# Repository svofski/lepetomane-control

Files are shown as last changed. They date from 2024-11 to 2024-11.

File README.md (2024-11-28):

# Pétocontrôle

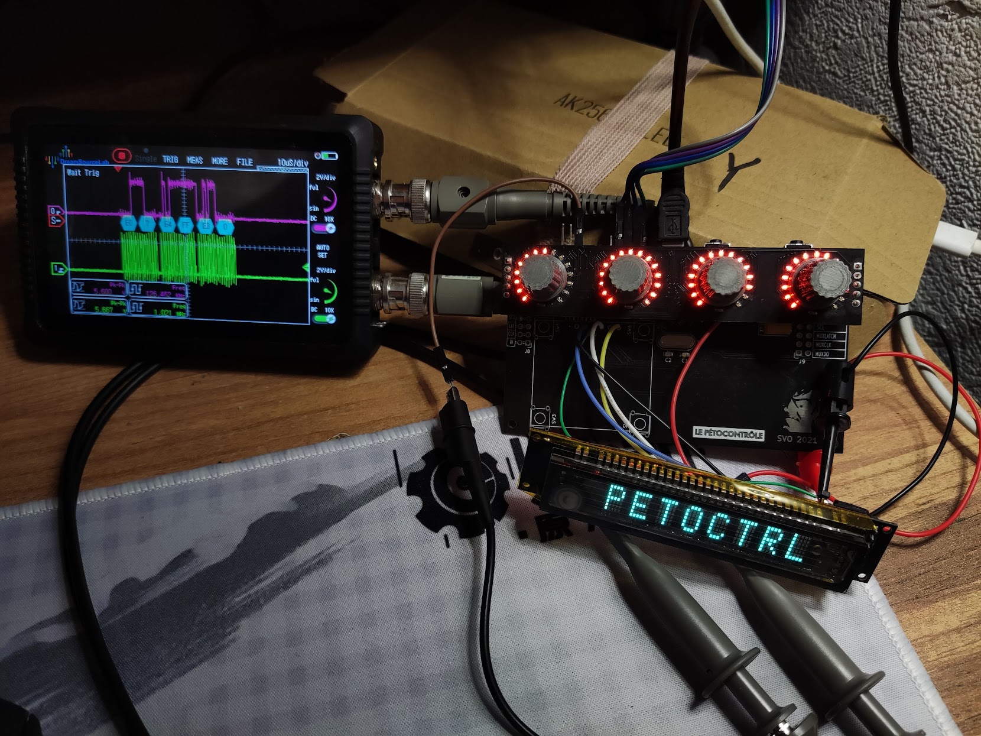
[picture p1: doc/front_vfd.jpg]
front


This is a MIDI control surface that sends CC messages when you turn the knobs. The main features are:

 * magnetic encoders (AS5600) with real potentiometer mechanics for ultra-smooth potentiometer-like feel
 * beautiful 0402 orange LEDs that show knob positions
 * Futaba 8-MD-06INKM VFD display

I wanted smooth feel encoders that work like proper potentiometers. These days everything is implemented using notchy encoders and although smooth input encoders do exist, they are somewhat uncommon.

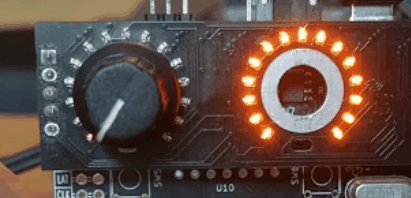
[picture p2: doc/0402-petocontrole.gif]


The design consists of two boards, the bottom one has MCU and the sensors, the top "mezzanine" board has the shift registers for the LEDs and holes for the knob shafts. 
The knobs are mechanisms ripped out from cheap potentiometers, they have little magnets glued into their bottom ends. Several boards can in theory attach to one another to form long strips of knobs.

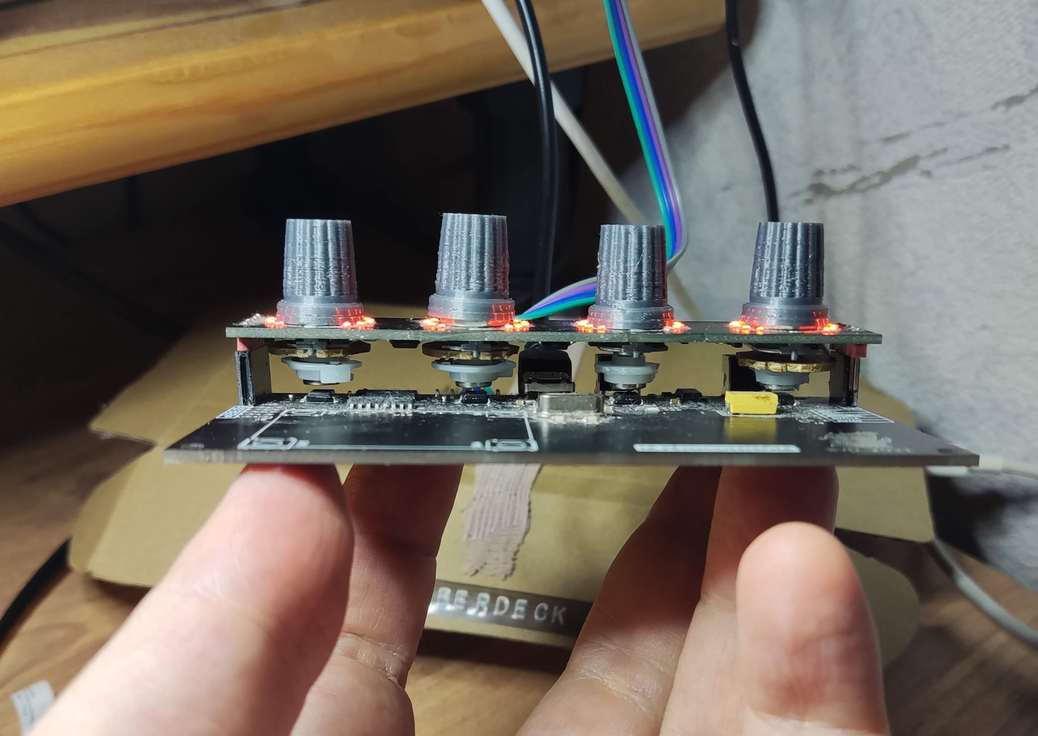
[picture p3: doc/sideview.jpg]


## Design files
 * [Schematics and PCB (KiCanvas)](https://kicanvas.org/?github=https://github.com/svofski/lepetomane-control/tree/master/kicad)

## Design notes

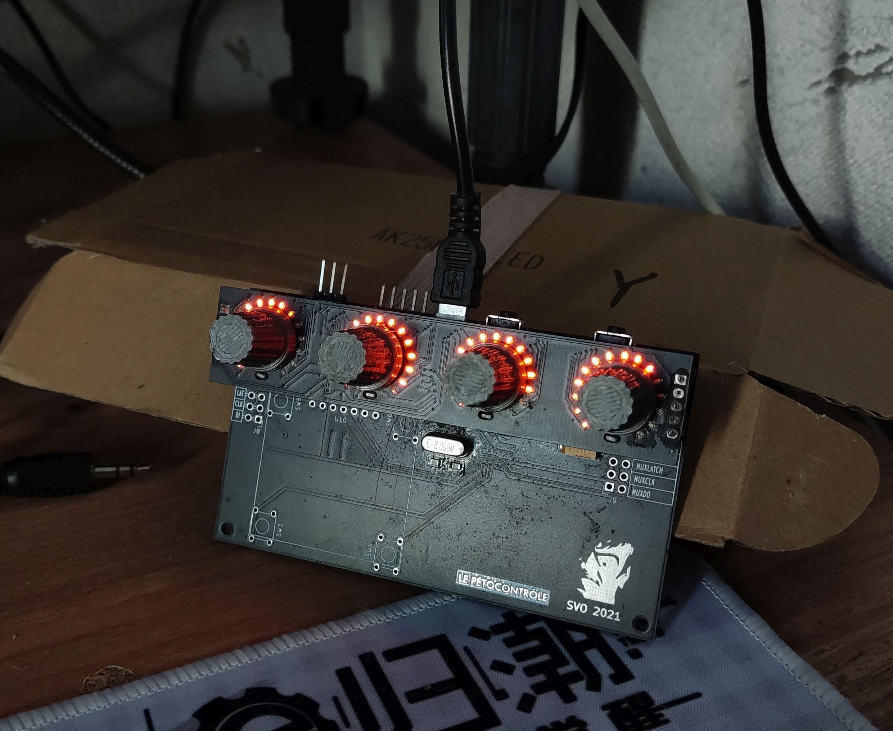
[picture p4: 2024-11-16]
doc/front.jpg

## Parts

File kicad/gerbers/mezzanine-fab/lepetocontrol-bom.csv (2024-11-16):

Comment | Designator | Footprint | LCSC
LED | D1,D2,D3,D4,D5,D6,D7,D8,D9,D10,D11,D12,D13,D14,D15,D17,D18,D19,D20,D21,D22,D23,D24,D25,D26,D27,D28,D29,D30,D31,D33,D34,D35,D36,D37,D38,D39,D40,D41,D42,D43,D44,D45,D46,D47,D49,D50,D51,D52,D53,D54,D55,D56,D57,D58,D59,D60,D61,D62,D63 | LED_0402 | C130720

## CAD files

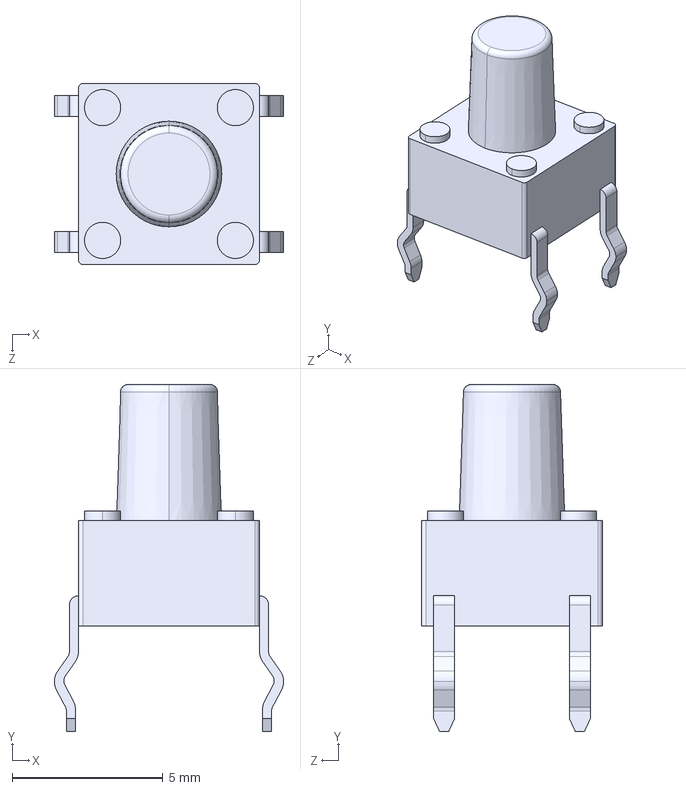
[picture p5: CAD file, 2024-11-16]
kicad/shapes3D/6x6button.STEP
7.60 x 11.5 x 6.00 mm

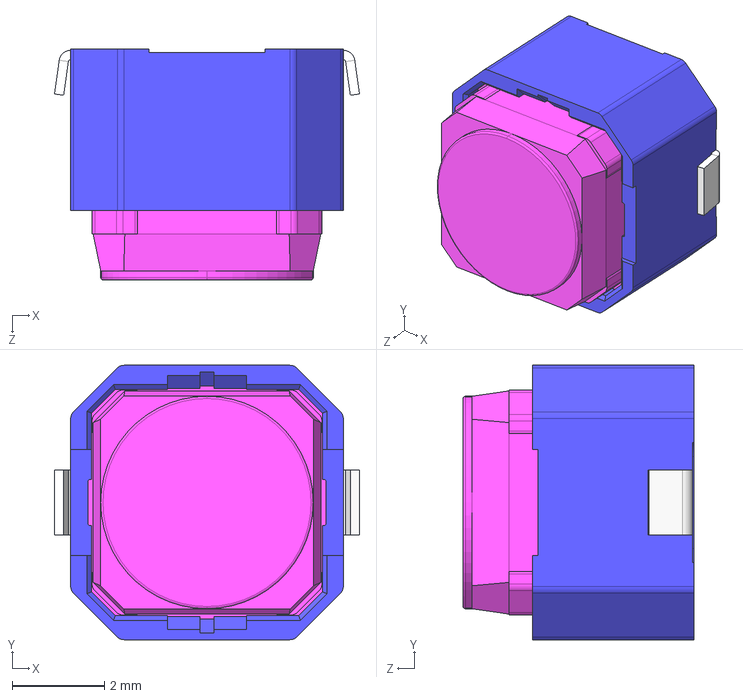
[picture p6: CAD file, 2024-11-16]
kicad/shapes3D/SKPMAM.STEP
6.60 x 5.94 x 5.00 mm

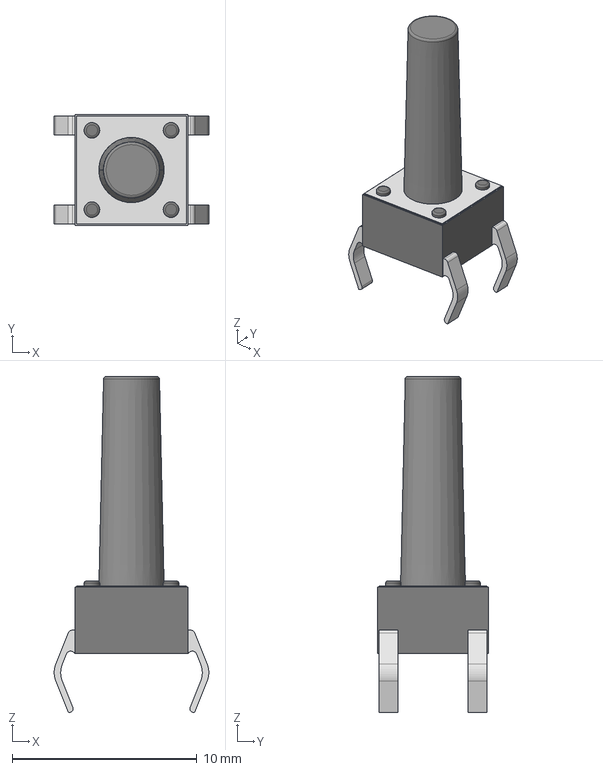
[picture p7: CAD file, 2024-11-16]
kicad/shapes3D/Tactal Switch -Thru (6mmx 6mmx15.0mm).stp
8.37 x 5.99 x 18.2 mm

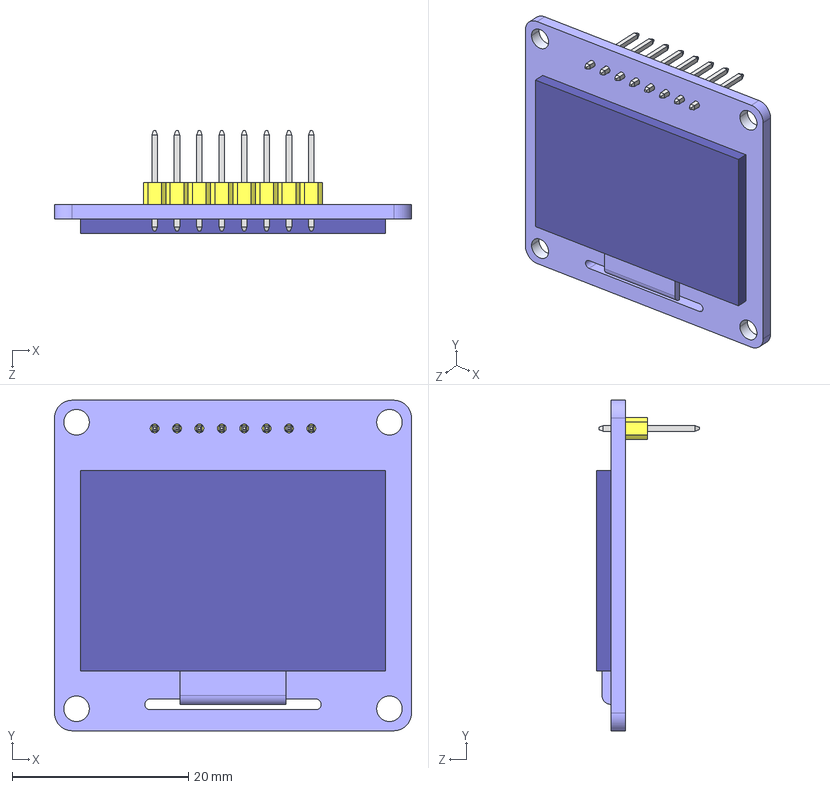
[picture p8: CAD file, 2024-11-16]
kicad/shapes3D/OLED_1.3inch_sh1106.STEP
40.5 x 37.5 x 11.6 mm
OLED_pcb_1.3
2.54mm_pin_header x 8

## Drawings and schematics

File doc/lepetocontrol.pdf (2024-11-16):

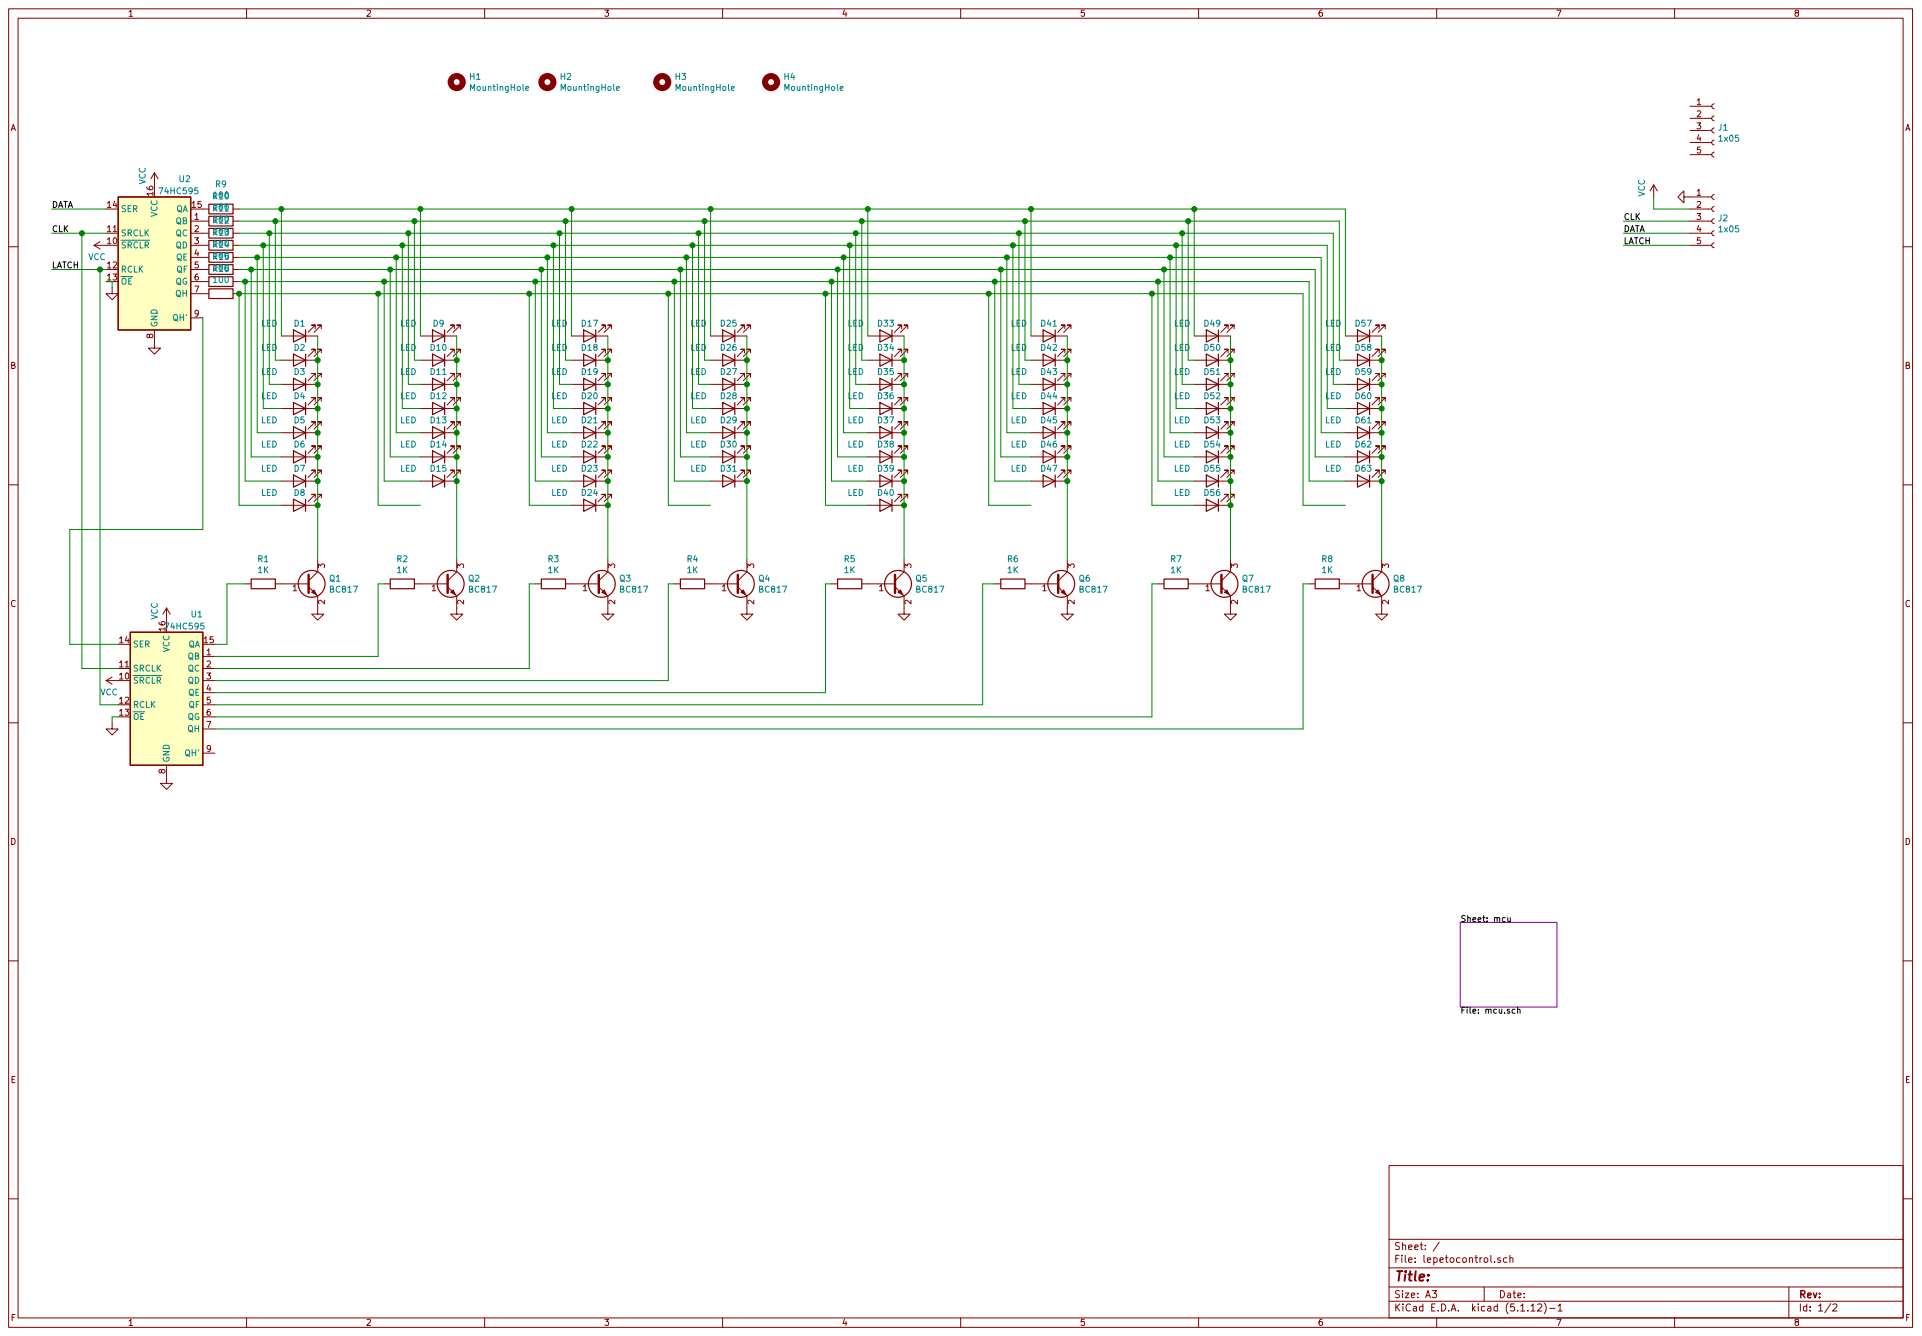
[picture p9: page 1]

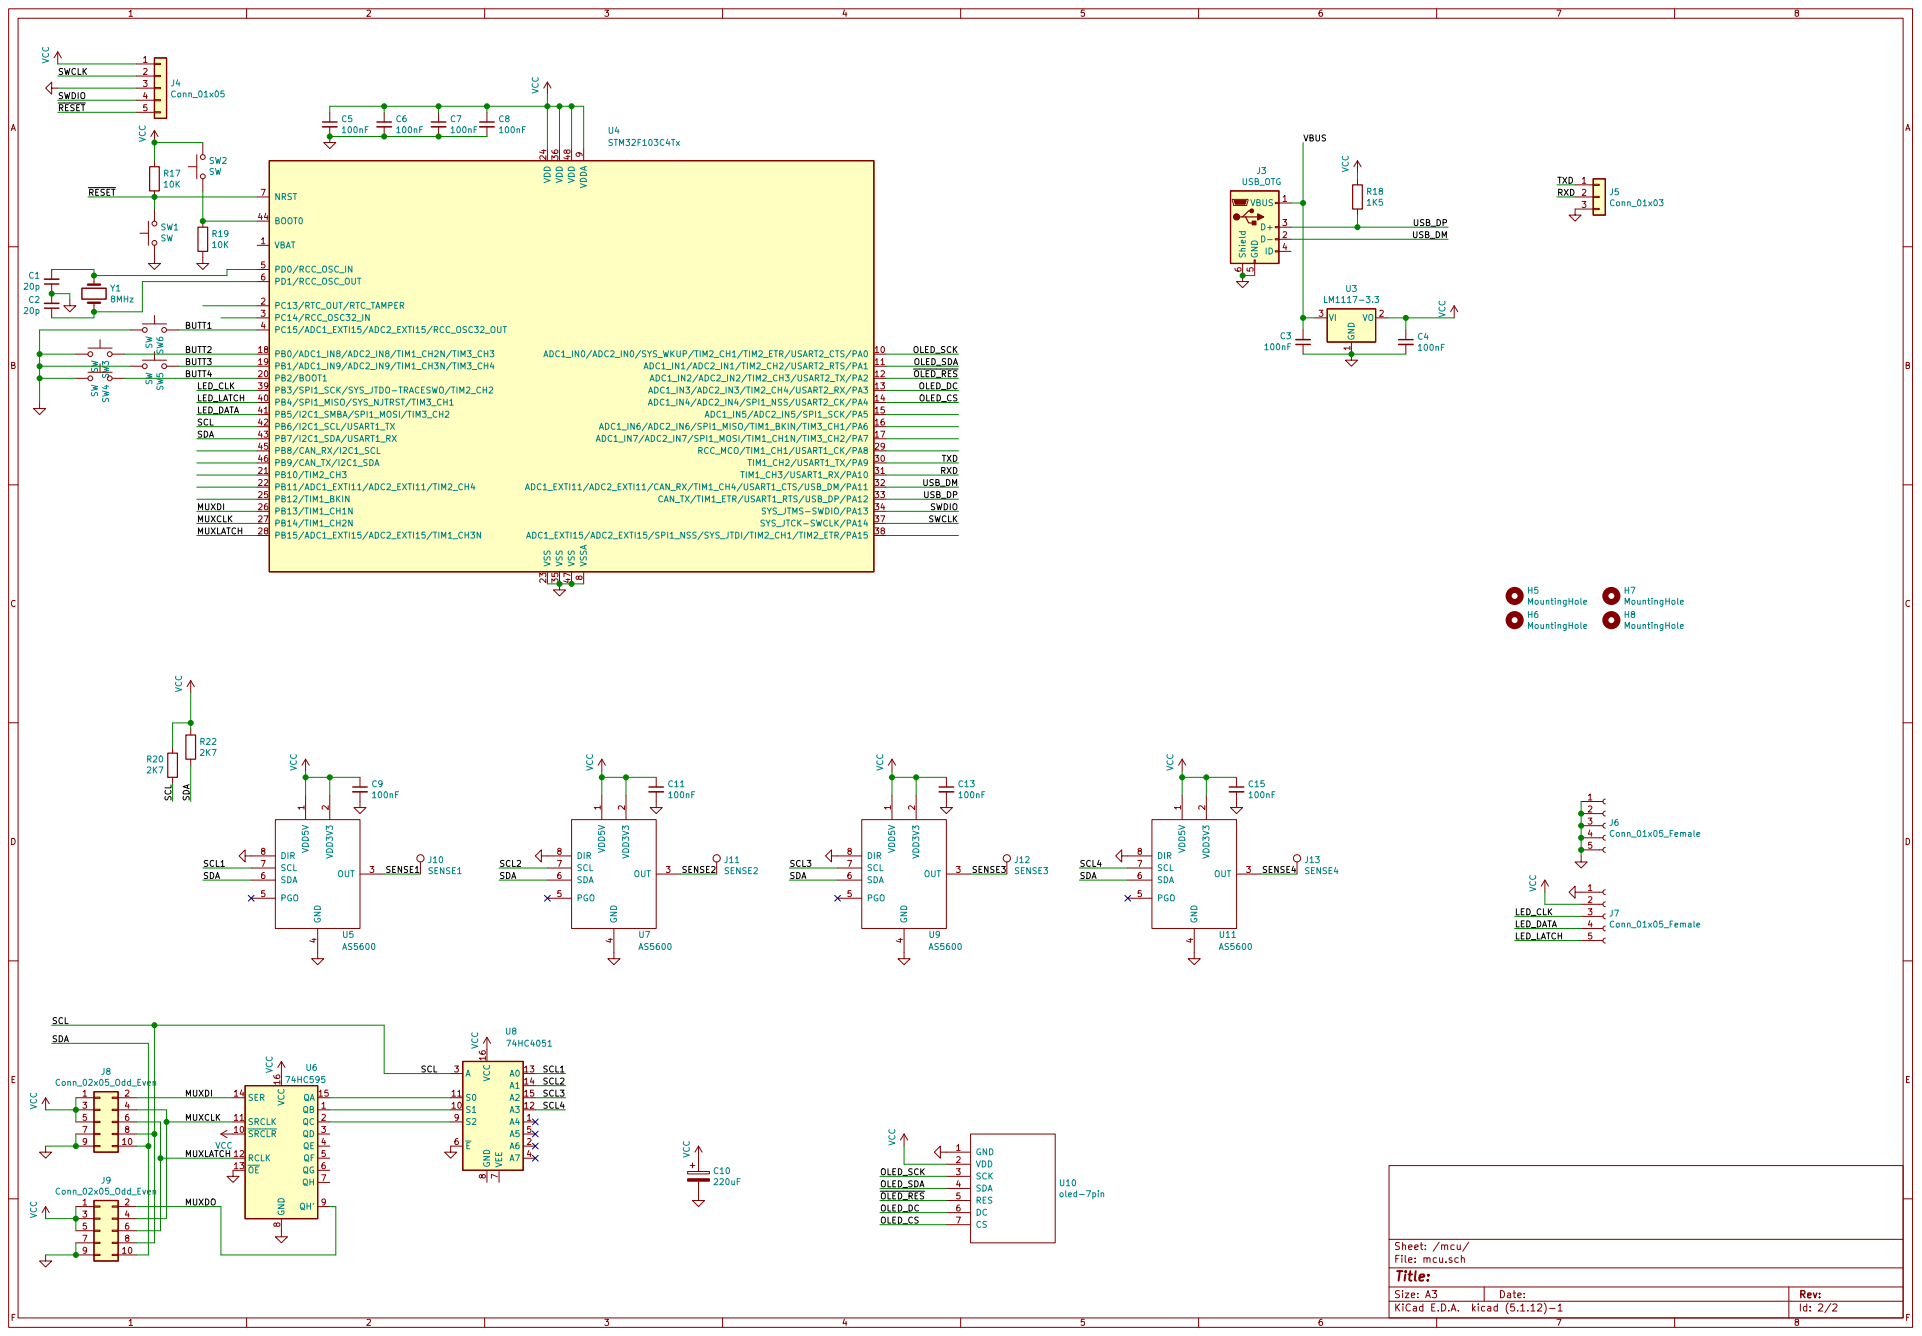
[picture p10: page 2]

9 VSS 23 VSS 35 VSS 47 VSSA

4 PGO 5 SDA 6 SCL 7 DIR 8 U7AS5600 VCC VCC

4 PGO 5 SDA 6 SCL 7 DIR 8 U9AS5600 VCCR20

4 PGO 5 SDA 6 SCL 7 DIR 8 U11 AS5600 VCC

4 PGO 5 SDA 6 SCL 7 DIR 8 U5AS5600 VDD5V

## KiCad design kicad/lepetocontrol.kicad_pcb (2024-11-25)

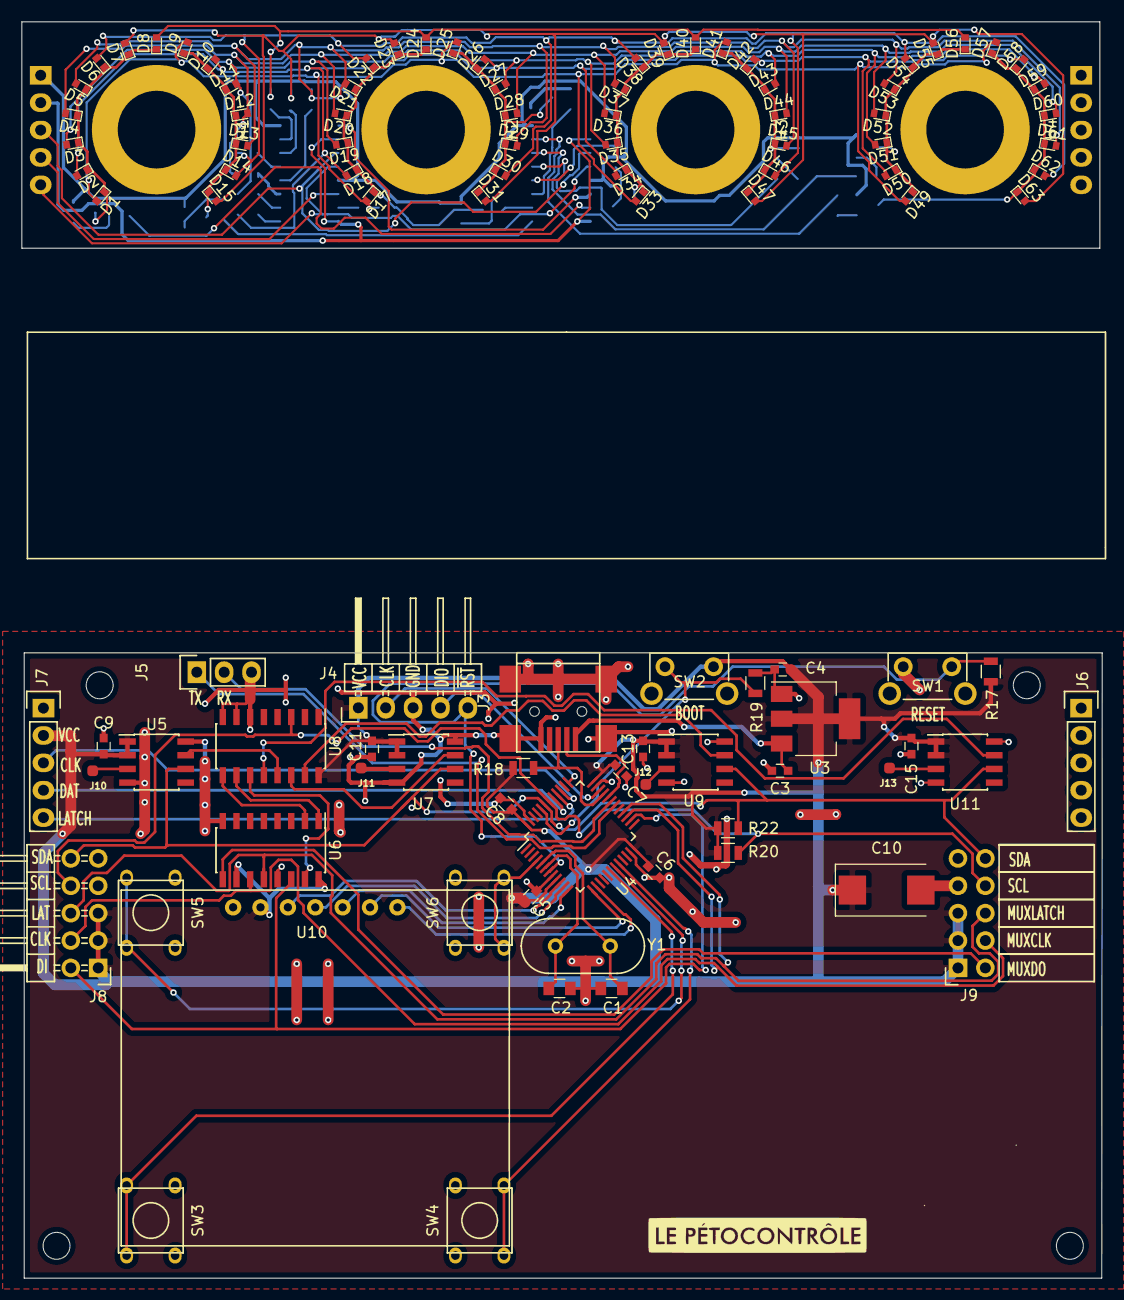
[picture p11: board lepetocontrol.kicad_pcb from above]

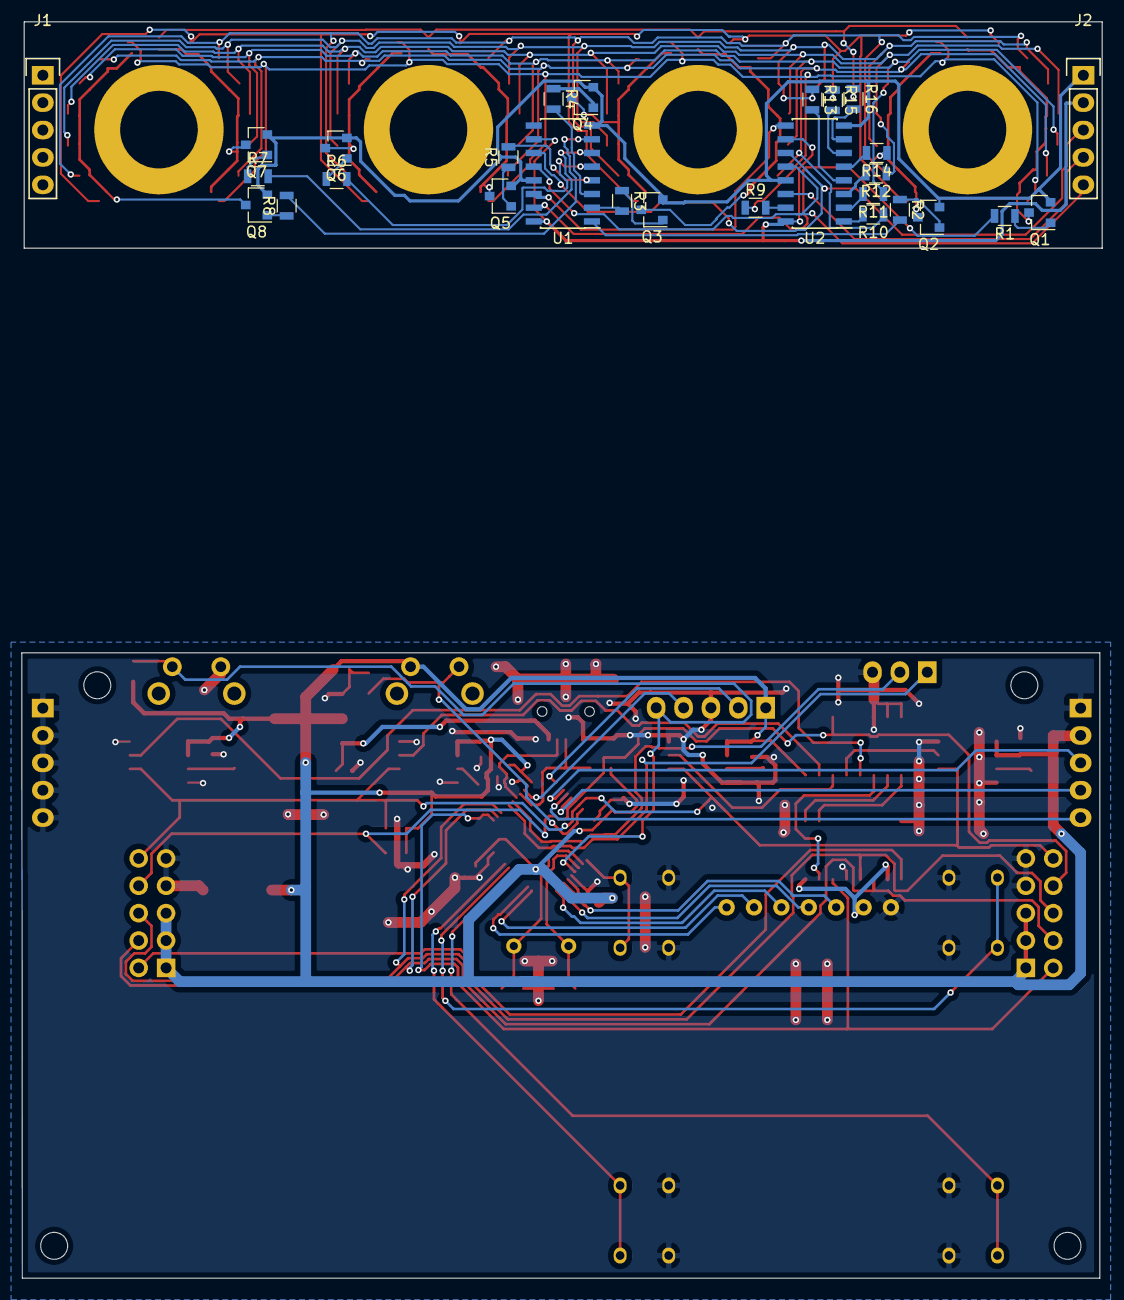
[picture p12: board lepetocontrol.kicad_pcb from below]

Board: 2 copper layers, 100.2 x 116.5 mm, 142 parts (28 on the bottom side), 86 nets.

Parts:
C1, C2: 20p; C_0805
C3, C4, C5, C6, C7, C8, C9, C11, C13, C15: 100nF; C_0603
C10: 220uF; CP_Tantalum_Case-D_EIA-7343-31_Reflow
D1, D2, D3, D4, D5, D6, D7, D8, D9, D10, D11, D12, D13, D14, D15, D17, D18, D19, D20, D21, D22, D23, D24, D25, D26, D27, D28, D29, D30, D31, D33, D34, D35, D36, D37, D38, D39, D40, D41, D42, D43, D44, D45, D46, D47, D49, D50, D51, D52, D53, D54, D55, D56, D57, D58, D59, D60, D61, D62, D63: LED; LED_0402
H1, H2, H3, H4: MountingHole; pot-mounting-hole
H5, H6, H7, H8: MountingHole; MountingHole_2.5mm
J1, J2: 1x05; Pin_Header_Straight_1x05
J3: USB_OTG; USB_Mini-B
J4: Conn_01x05; Pin_Header_Angled_1x05
J5: Conn_01x03; Pin_Header_Straight_1x03
J6, J7: Conn_01x05_Female; Socket_Strip_Straight_1x05
J8: Conn_02x05_Odd_Even; Pin_Header_Angled_2x05
J9: Conn_02x05_Odd_Even; Socket_Strip_Angled_2x05
J10: SENSE1; WIREPAD_SMD_TINY
J11: SENSE2; WIREPAD_SMD_TINY
J12: SENSE3; WIREPAD_SMD_TINY
J13: SENSE4; WIREPAD_SMD_TINY
MEZZANINE: lepetocontrol-mezzanine
Q1, Q2, Q3, Q4, Q5, Q6, Q7, Q8: BC817; SOT-23
R1, R2, R3, R4, R5, R6, R7, R8: 1K; R_0805
R9, R10, R11, R12, R13, R14, R15, R16: 100; R_0805
R17, R19: 10K; R_0805
R18: 1K5; R_0805
R20, R22: 2K7; R_0805
SW1, SW2: SW; SW_Tactile_SPST_Angled
SW3, SW4, SW5, SW6: SW; switch_6x6
U1, U2, U6: 74HC595; SOIC-16_3.9x9.9mm_Pitch1.27mm
U3: LM1117-3.3; SOT-223-3Lead_TabPin2
U4: STM32F103C4Tx; LQFP-48_7x7mm_Pitch0.5mm
U5, U7, U9, U11: AS5600; SOIC-8_3.9x4.9mm_Pitch1.27mm
U8: 74HC4051; SOIC-16_3.9x9.9mm_Pitch1.27mm
U10: oled-7pin; oled_1.3_spi
Y1: 8MHz; HC-49V

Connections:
/CLK: J2.3, U1.11, U2.11
/DATA: J2.4, U2.14
/LATCH: J2.5, U1.12, U2.12
/mcu/BUTT1: SW6.2, U4.4
/mcu/BUTT2: SW3.2, U4.18
/mcu/BUTT3: SW5.2, U4.19
/mcu/BUTT4: SW4.2, U4.20
/mcu/LED_CLK: J7.3, U4.39
/mcu/LED_DATA: J7.4, U4.41
/mcu/LED_LATCH: J7.5, U4.40
/mcu/MUXCLK: J8.4, J9.4, U4.27, U6.11
/mcu/MUXDI: J8.2, U4.26, U6.14
/mcu/MUXDO: J9.2, U6.9
/mcu/MUXLATCH: J8.6, J9.6, U4.28, U6.12
/mcu/OLED_CS: U4.14, U10.7
/mcu/OLED_DC: U4.13, U10.6
/mcu/OLED_SCK: U4.10, U10.3
/mcu/OLED_SDA: U4.11, U10.4
/mcu/RXD: J5.2, U4.31
/mcu/SCL: J8.8, J9.8, R20.1, U4.42, U8.3
/mcu/SCL1: U5.7, U8.13
/mcu/SCL2: U7.7, U8.14
/mcu/SCL3: U8.15, U9.7
/mcu/SCL4: U8.12, U11.7
/mcu/SDA: J8.10, J9.10, R22.2, U4.43, U5.6, U7.6, U9.6, U11.6
/mcu/SENSE1: J10.1, U5.3
/mcu/SENSE2: J11.1, U7.3
/mcu/SENSE3: J12.1, U9.3
/mcu/SENSE4: J13.1, U11.3
/mcu/SWCLK: J4.2, U4.37
/mcu/SWDIO: J4.4, U4.34
/mcu/TXD: J5.1, U4.30
/mcu/USB_DM: J3.2, U4.32
/mcu/USB_DP: J3.3, R18.2, U4.33
/mcu/VBUS: C3.2, J3.1, U3.3
/mcu/~OLED_RES: U4.12, U10.5
/mcu/~RESET: J4.5, R17.2, SW1.2, U4.7
GND: C1.1, C2.2, C3.1, C4.2, C5.2, C6.2, C7.2, C8.2, C9.2, C10.2, C11.2, C13.2, C15.2, J2.1, J3.5, J3.6, J4.3, J5.3, J6.1, J6.2, J6.3, J6.4, J6.5, J7.1, J8.7, J8.9, J9.7, J9.9, Q1.2, Q2.2, Q3.2, Q4.2, Q5.2, Q6.2, Q7.2, Q8.2, R19.2, SW1.1, SW3.1, SW4.1, SW5.1, SW6.1, U1.8, U1.13, U2.8, U2.13, U3.1, U4.8, U4.23, U4.35, U4.47, U5.4, U5.8, U6.8, U6.13, U7.4, U7.8, U8.6, U8.7, U8.8, U9.4, U9.8, U10.1, U11.4, U11.8
unnamed: C1.2, U4.5, Y1.1
unnamed: C2.1, U4.6, Y1.2
unnamed: D1.1, D2.1, D3.1, D4.1, D5.1, D6.1, D7.1, D8.1, Q1.3
unnamed: D1.2, D9.2, D17.2, D25.2, D33.2, D41.2, D49.2, D57.2, R9.1
unnamed: D9.1, D10.1, D11.1, D12.1, D13.1, D14.1, D15.1, Q2.3
unnamed: D2.2, D10.2, D18.2, D26.2, D34.2, D42.2, D50.2, D58.2, R10.1
unnamed: D3.2, D11.2, D19.2, D27.2, D35.2, D43.2, D51.2, D59.2, R11.1
unnamed: D4.2, D12.2, D20.2, D28.2, D36.2, D44.2, D52.2, D60.2, R12.1
unnamed: D5.2, D13.2, D21.2, D29.2, D37.2, D45.2, D53.2, D61.2, R13.1
unnamed: D6.2, D14.2, D22.2, D30.2, D38.2, D46.2, D54.2, D62.2, R14.1
unnamed: D7.2, D15.2, D23.2, D31.2, D39.2, D47.2, D55.2, D63.2, R15.1
unnamed: D17.1, D18.1, D19.1, D20.1, D21.1, D22.1, D23.1, D24.1, Q3.3
unnamed: D8.2, D24.2, D40.2, D56.2, R16.1
unnamed: D25.1, D26.1, D27.1, D28.1, D29.1, D30.1, D31.1, Q4.3
unnamed: D33.1, D34.1, D35.1, D36.1, D37.1, D38.1, D39.1, D40.1, Q5.3
unnamed: D41.1, D42.1, D43.1, D44.1, D45.1, D46.1, D47.1, Q6.3
unnamed: D49.1, D50.1, D51.1, D52.1, D53.1, D54.1, D55.1, D56.1, Q7.3
unnamed: D57.1, D58.1, D59.1, D60.1, D61.1, D62.1, D63.1, Q8.3
unnamed: Q1.1, R1.1
unnamed: Q2.1, R2.1
unnamed: Q3.1, R3.1
unnamed: Q4.1, R4.1
unnamed: Q5.1, R5.1
unnamed: Q6.1, R6.1
unnamed: Q7.1, R7.1
unnamed: Q8.1, R8.1
unnamed: R1.2, U1.15
unnamed: R2.2, U1.1
unnamed: R3.2, U1.2
unnamed: R4.2, U1.3
unnamed: R5.2, U1.4
unnamed: R6.2, U1.5
unnamed: R7.2, U1.6
unnamed: R8.2, U1.7
unnamed: R9.2, U2.15
unnamed: R10.2, U2.1
unnamed: R11.2, U2.2
unnamed: R12.2, U2.3
unnamed: R13.2, U2.4
unnamed: R14.2, U2.5
unnamed: R15.2, U2.6
unnamed: R16.2, U2.7
unnamed: R19.1, SW2.1, U4.44
unnamed: U1.14, U2.9
unnamed: U6.1, U8.10
unnamed: U6.2, U8.9
unnamed: U6.15, U8.11
VCC: C4.1, C5.1, C6.1, C7.1, C8.1, C9.1, C10.1, C11.1, C13.1, C15.1, J2.2, J4.1, J7.2, J8.1, J8.3, J8.5, J9.1, J9.3, J9.5, R17.1, R18.1, R20.2, R22.1, SW2.2, U1.10, U1.16, U2.10, U2.16, U3.2, U4.9, U4.24, U4.36, U4.48, U5.1, U5.2, U6.10, U6.16, U7.1, U7.2, U8.16, U9.1, U9.2, U10.2, U11.1, U11.2

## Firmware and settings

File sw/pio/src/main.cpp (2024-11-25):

// Petocontrole
//
// MIDI knobs and blinkenlights
// blessed with a VFD display
//
// svofski 2024

#include "params.h"

#include <libopencm3/stm32/rcc.h>
#include <libopencm3/stm32/gpio.h>
#include <libopencm3/stm32/usart.h>
#include <libopencm3/stm32/spi.h>
#include <libopencm3/stm32/i2c.h>
#include <libopencm3/cm3/nvic.h>

//#include "usrat.h"
#include "xprintf.h"
#include "borat.h"
#include "usbcmp.h"
#include "midi.h"
#include "AS5600.h"
#include "i2cmux.h"
#include "ledrefresh.h"
#include "knob.h"
#include "knobulator.h"

#if WITH_VFD
#include "swspi.h"
#include "vfddrv.h"
#include "display.h"
#endif

#include <cmath>

extern bool usb_configured_flag;

AMS_5600 as5600;
Knobulator knobulator(as5600);

void my_midi_peak_meter_cb(midi_chan_t midichan, uint8_t chan, uint8_t value)
{
    (void)midichan;
    knobulator.set_peak(chan, value);
}

#if WITH_VFD
SW_SPI vfd_spi(/*port*/ GPIOA, /*clk*/GPIO0, /*miso*/-1, /*MOSI*/GPIO1);
VFD_8MD06INKM<SW_SPI> vfddrv(vfd_spi, GPIOA, /*cs*/GPIO4, /*reset*/GPIO2);
Display<VFD_8MD06INKM<SW_SPI>> vfd(vfddrv);
#endif

void knobulator_changed(int cc, int val)
{
    if (cc >= 0 && cc < 100 && val >= 0 && val < 1000) {
        xsprintf(vfd.text(), "CC%02d:%03d", cc, val);
    }
    else if (cc >= 100 && val >= 0 && val < 1000) {
        xsprintf(vfd.text(), "C%03d:%03d", cc, val);
    }
    vfd.invalidate();
    xprintf("%d %d '%s'\n", cc, val, vfd.text()); // dead without this line
}

int main(void)
{
    // reacts to CC91..CC94 to update peaks
    midi_peak_meter_cb = my_midi_peak_meter_cb;

    clock_setup();
    gpio_setup();
    usbcmp_setup();
    wire_begin();
    rcc_periph_clock_disable(RCC_I2C1);
    knobulator.setup();
    knobulator.on_changed = knobulator_changed;

#if WITH_VFD
    vfd.init();
#endif

    int skip_ctr = 0;
    while (1) {
        // no idea, seems to make it a bit more stable
        if (++skip_ctr == 32) {
            usbcmp_poll();
            skip_ctr = 0;

            vfd.animate();
        }
        knobulator.loop();
    }

    return 0;
}

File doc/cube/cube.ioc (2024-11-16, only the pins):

Mcu.UserName=STM32F103C6Tx
PA0-WKUP.GPIO_Label=OLED_SCK
PA0-WKUP.Signal=GPIO_Output
PA1.GPIO_Label=OLED_SDA
PA1.Signal=GPIO_Output
PA10.Signal=USART1_RX
PA11.Signal=USB_DM
PA12.Signal=USB_DP
PA13.Signal=SYS_JTMS-SWDIO
PA14.Signal=SYS_JTCK-SWCLK
PA15.GPIO_Label=SDA
PA15.Signal=GPIO_Output
PA2.GPIO_Label=OLED_RES
PA2.Signal=GPIO_Output
PA3.GPIO_Label=OLED_DC
PA3.Signal=GPIO_Output
PA4.GPIO_Label=OLED_CS
PA4.Signal=GPIO_Output
PA9.Signal=USART1_TX
PB0.GPIO_Label=BUTT2
PB0.Signal=GPIO_Input
PB1.GPIO_Label=BUTT3
PB1.Signal=GPIO_Input
PB10.GPIO_Label=SCL3
PB10.Signal=GPIO_Input
PB11.GPIO_Label=SCL4
PB11.Signal=GPIO_Input
PB12.GPIO_Label=SCL5
PB12.Signal=GPIO_Input
PB13.GPIO_Label=SCL6
PB13.Signal=GPIO_Input
PB14.GPIO_Label=SCL7
PB14.Signal=GPIO_Input
PB15.GPIO_Label=SCL8
PB15.Signal=GPIO_Input
PB2.GPIO_Label=BUTT3
PB2.Signal=GPIO_Input
PB3.Signal=SPI1_SCK
PB4.GPIO_Label=LED_LATCH
PB4.Signal=GPIO_Output
PB5.Signal=SPI1_MOSI
PB6.Signal=I2C1_SCL
PB7.Signal=I2C1_SDA
PB8.GPIO_Label=SCL1
PB8.Signal=GPIO_Input
PB9.GPIO_Label=SCL2
PB9.Signal=GPIO_Input
PC13-TAMPER-RTC.GPIO_Label=OLED_RST
PC13-TAMPER-RTC.Signal=GPIO_Output
PC15-OSC32_OUT.GPIO_Label=BUTT1
PC15-OSC32_OUT.Signal=GPIO_Input
PD0-OSC_IN.Signal=RCC_OSC_IN
PD1-OSC_OUT.Signal=RCC_OSC_OUT

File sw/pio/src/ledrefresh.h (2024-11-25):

// LED refresher for petocontrole
//
// The LEDs are arranged in a 8x8 matrix (row 7 of odd columns is absent).
// Consult the schematics for details.
//
// svofski 2024

#pragma once

#include "params.h"

#include <cstdint>
#include <libopencm3/stm32/gpio.h>
#include <libopencm3/stm32/spi.h>

void spi_reset(int dev)
{
    switch (dev) {
        case SPI1:
            rcc_periph_reset_pulse(RST_SPI1);
            break;
        case SPI2:
            rcc_periph_reset_pulse(RST_SPI2);
            break;
        default:
            for(;;);
    }
}


// LED_CLK      PB3     SPI1_SCK (remapped)
// LED_LATCH    PB4     (GPIO)
// LED_DATA     PB5     SPI1_MOSI (remapped)
//template<int N_KNOBS, int N_LED_GROUPS>
struct LedRefresh {
    static constexpr uint32_t gpio_port = GPIOB;
    static constexpr uint32_t gpio_clk = GPIO3,
                       gpio_latch = GPIO4,
                       gpio_data = GPIO5; 

    union {
        uint8_t bitmap[N_LED_GROUPS]; // LED matrix columns
        uint16_t bitmap16[N_KNOBS];   // each knob has 15 leds (2 columns)
    };

    int index;

    LedRefresh() : bitmap{}, index(0) {}

    void init()
    {
        /* Enable Alternate Function clock. */
	rcc_periph_clock_enable(RCC_AFIO);
        /* Enable SPI1 clock */
        rcc_periph_clock_enable(RCC_SPI1);

        /* remap SPI1 to PB3..5 */
        gpio_primary_remap(AFIO_MAPR_SWJ_CFG_JTAG_OFF_SW_ON, AFIO_MAPR_SPI1_REMAP);
        
        gpio_set_mode(gpio_port, GPIO_MODE_OUTPUT_50_MHZ,
            GPIO_CNF_OUTPUT_ALTFN_PUSHPULL, gpio_clk | gpio_data | gpio_latch );

        spi_reset(SPI1);

        spi_init_master(SPI1, 
                SPI_CR1_BAUDRATE_FPCLK_DIV_16, 
                SPI_CR1_CPOL_CLK_TO_0_WHEN_IDLE,
                SPI_CR1_CPHA_CLK_TRANSITION_2,
                SPI_CR1_DFF_16BIT,
                SPI_CR1_MSBFIRST);

        spi_set_bidirectional_transmit_only_mode(SPI1);

        // examples have this but i don't know why...
        spi_enable_software_slave_management(SPI1);
        spi_set_nss_high(SPI1);

        spi_enable(SPI1);

        gpio_set_mode(gpio_port, GPIO_MODE_OUTPUT_50_MHZ,
                GPIO_CNF_OUTPUT_PUSHPULL, gpio_latch);
    }

    void latch(int on)
    {
        if (on) {
            gpio_set(gpio_port, gpio_latch);
            for (unsigned i = 0; i < 5; ++i) { __asm__("nop"); }
        }
        else {
            gpio_clear(gpio_port, gpio_latch);
            for (unsigned i = 0; i < 35; ++i) { __asm__("nop"); }
        }
    }

    void strobe()
    {
        latch(0);
        latch(1);
        latch(0);
    }

    // iterate with 1 as column selector (group) in msb and bitmap as rows in lsb
    void refresh()
    {
        spi_send(SPI1, 0);
        latch(1);
        latch(0);

        spi_send(SPI1, (1 << (index + 8)) | bitmap[index]);
        latch(1);
        latch(0);

        ++index;
        if (index == N_LED_GROUPS) {
            index = 0;
        }
    }

    void off()
    {
        spi_send(SPI1, 0);
        strobe();
    }
};

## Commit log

2024-11-16 first commit from salvaged pieces
    everything needs a lot of cleanup before this can continue. but it
    builds, the leds shine beautifully and it sends midi cc messages.
    [6x6button.STEP, OLED_1.3inch_sh1106.STEP, SKPMAM.STEP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]
2024-11-25 wip wip wip
    kicad files updated to version 8
    vfd added
    [lepetocontrol.kicad_pcb, lepetocontrol.kicad_sch, lepetocontrol.sch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]
